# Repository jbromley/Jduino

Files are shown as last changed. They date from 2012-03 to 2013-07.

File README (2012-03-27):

Jduino
======

These are the design files (EAGLE 6) for a simple, homebrew Arduino
clone. It uses the Arduino clone from chapter 6 of _Arduino Robotics_
and seeks to make a smaller board that preserves the Arduino
outline. Additionally, I hope to add the following features:

 * power switch,
 * power protection diode,
 * smaller L4931 LDO voltage regulator,
 * right angle FTDI port on edge of board so programming can be done
   with a shield attached.

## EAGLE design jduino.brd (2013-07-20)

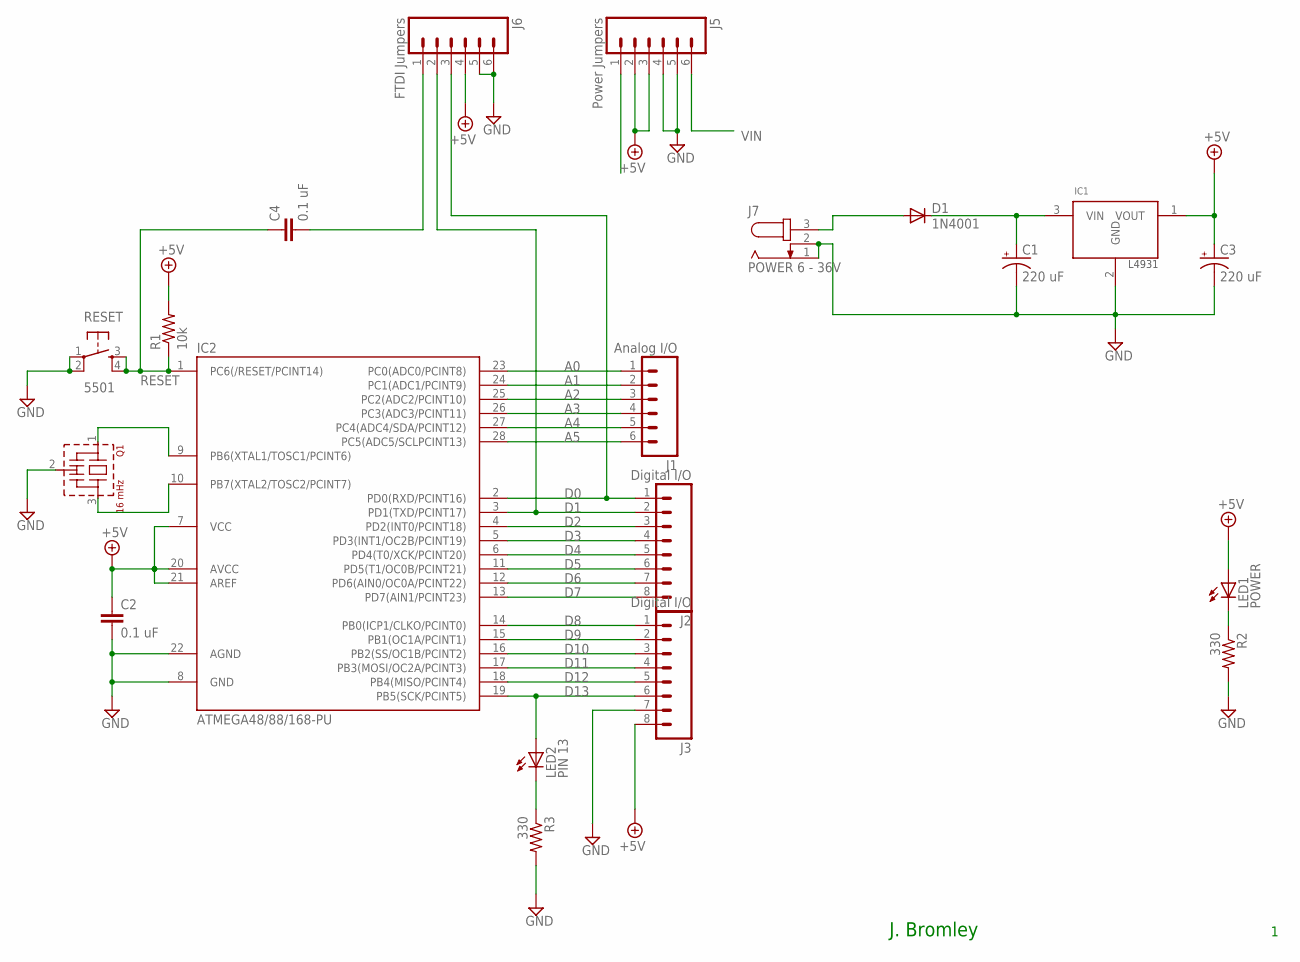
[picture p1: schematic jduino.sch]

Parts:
C1, C3: 220 uF; CPOL-RADIAL-10UF-25V
C2, C4: 0.1 uF; CAP-PTH-SMALL
D1: 1N4001; DIODE-1N4001
IC1: L4931; TO-92
IC2: ATMEGA48/88/168-PU; DIL28-3
J1: Analog I/O; 1X06
J2, J3: Digital I/O; 1X08
J5: Power Jumpers; 1X06
J6: FTDI Jumpers; 1X06
J7: POWER 6 - 36V; SPC4078
LED1: POWER; LED3MM
LED2: PIN 13; LED3MM
Q1: 16 mHz; CSTLS_X
R1: 10k; AXIAL-0.3
R2, R3: 330; AXIAL-0.3
RESET: 5501; TACTILE-PTH

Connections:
+5V: C2.1, C3.1 (+), IC1.1 (VOUT), IC2.7 (VCC), IC2.20 (AVCC), IC2.21 (AREF), J3.8, J5.2, J5.3, J6.4, LED1.A, R1.P$2 (2)
A0: IC2.23 (PC0(ADC0/PCINT8)), J1.1
A1: IC2.24 (PC1(ADC1/PCINT9)), J1.2
A2: IC2.25 (PC2(ADC2/PCINT10)), J1.3
A3: IC2.26 (PC3(ADC3/PCINT11)), J1.4
A4: IC2.27 (PC4(ADC4/SDA/PCINT12)), J1.5
A5: IC2.28 (PC5(ADC5/SCLPCINT13)), J1.6
D0: IC2.2 (PD0(RXD/PCINT16)), J2.1, J6.3
D1: IC2.3 (PD1(TXD/PCINT17)), J2.2, J6.2
D2: IC2.4 (PD2(INT0/PCINT18)), J2.3
D3: IC2.5 (PD3(INT1/OC2B/PCINT19)), J2.4
D4: IC2.6 (PD4(T0/XCK/PCINT20)), J2.5
D5: IC2.11 (PD5(T1/OC0B/PCINT21)), J2.6
D6: IC2.12 (PD6(AIN0/OC0A/PCINT22)), J2.7
D7: IC2.13 (PD7(AIN1/PCINT23)), J2.8
D8: IC2.14 (PB0(ICP1/CLKO/PCINT0)), J3.1
D9: IC2.15 (PB1(OC1A/PCINT1)), J3.2
D10: IC2.16 (PB2(SS/OC1B/PCINT2)), J3.3
D11: IC2.17 (PB3(MOSI/OC2A/PCINT3)), J3.4
D12: IC2.18 (PB4(MISO/PCINT4)), J3.5
D13: IC2.19 (PB5(SCK/PCINT5)), J3.6, LED2.A
GND: C1.2 (-), C2.2, C3.2 (-), IC1.2 (GND), IC2.8 (GND), IC2.22 (AGND), J3.7, J5.4, J5.5, J6.5, J6.6, J7.1, J7.2, Q1.2 (VSS), R2.P$2 (2), R3.P$2 (2), RESET.1, RESET.2
unnamed: C4.2, J6.1
unnamed: D1.A, J7.3
unnamed: IC2.10 (PB7(XTAL2/TOSC2/PCINT7)), Q1.3
unnamed: LED2.K (C), R3.P$1 (1)
unnamed: IC2.9 (PB6(XTAL1/TOSC1/PCINT6)), Q1.1
unnamed: C1.1 (+), D1.C, IC1.3 (VIN)
unnamed: LED1.K (C), R2.P$1 (1)
RESET: C4.1, IC2.1 (PC6(/RESET/PCINT14)), J5.1, R1.P$1 (1), RESET.3, RESET.4
VIN: J5.6

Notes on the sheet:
J. Bromley

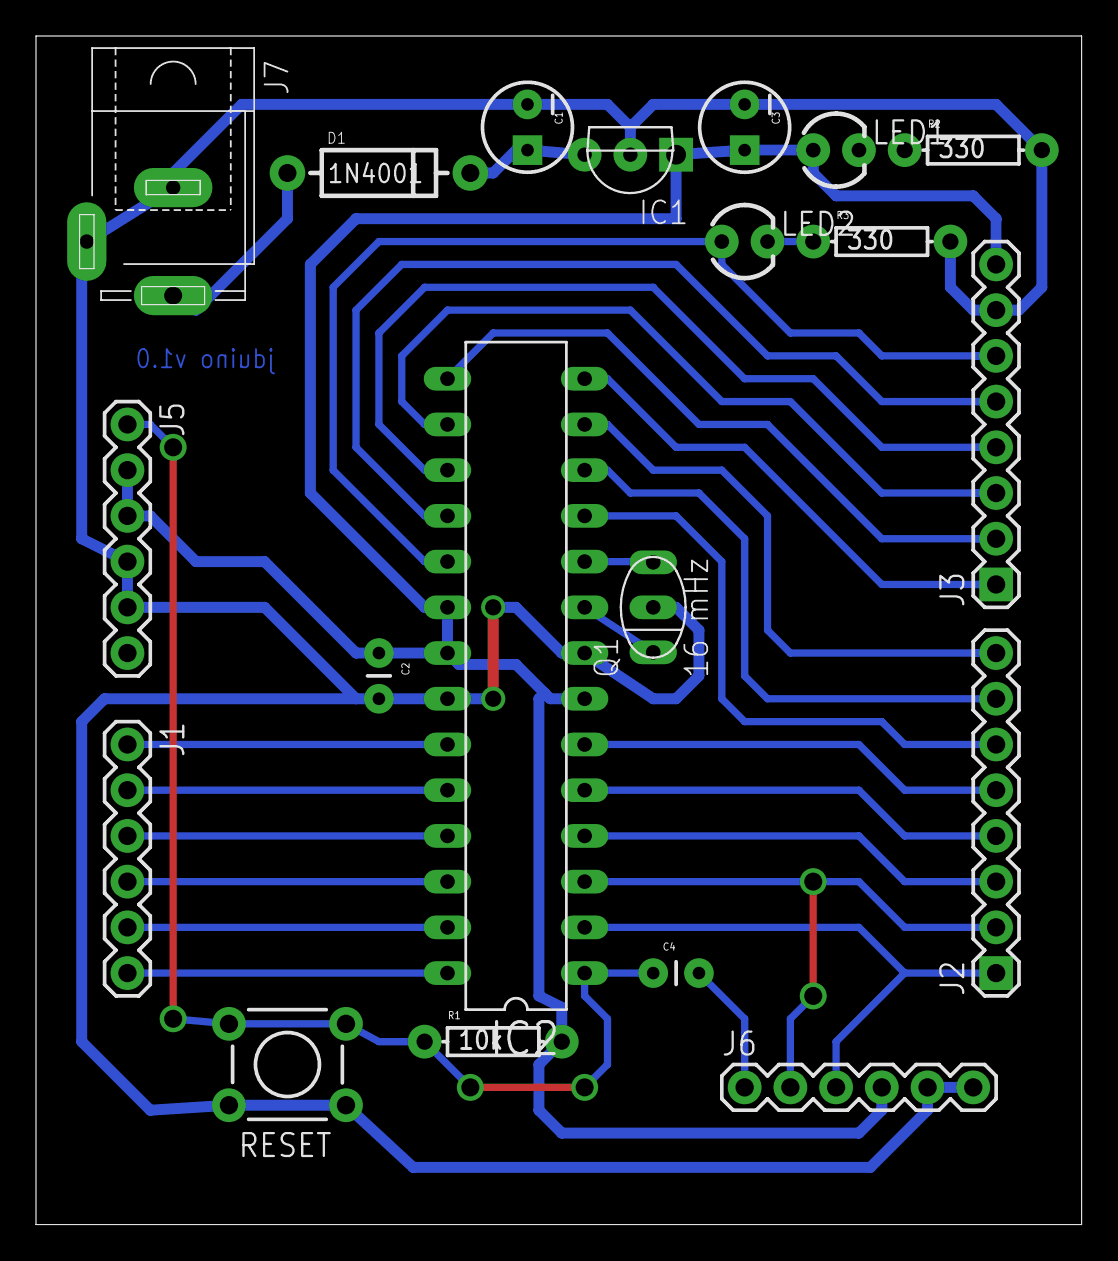
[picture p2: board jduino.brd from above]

Board: 2 copper layers, 58.1 x 66.0 mm, 20 parts (0 on the bottom side), 30 nets.

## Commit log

2012-03-27 Initial import.
    Initial import of the design files from the _Arduino Robotics_ book.
    [jduino.brd, jduino.sch]
2012-03-30 Added power elements.
    Added a protection diode and a power switch. Also swapped out the
    7805 for a LDO regulator.
    [jduino.brd, jduino.sch]
2012-03-30 Initial complete version.
    Routed D9 - D13, GND, and AREF to the headers. Rotated the FTDI
    header to be able to use a right angle header. Two jumpers remain.
    [jduino.brd]
2012-04-11 Replaced Euro-stype capacitors.
    Replaced the large reset capacitors with smaller-package 0.1 uF
    capacitors.
    [jduino.brd, jduino.sch]
2012-04-11 Hand routed some pins.
    I hand-routed pins 3 through 5 and 23 through 28, since these should
    be straight-shots. Then auto routed the remaining traces. The board
    still needs significant cleanup.
    [jduino.brd]
2012-04-12 Finished one-sided layout.
    Completed a one-sided layout of the board that only requires three
    jumpers.
    [jduino.brd, jduino.sch]
2012-04-12 Recentered circuit on board.
    That last revisions left some traces too near the edge of the
    board. Moved the circuit to have at least 0.1 inch clearance on all
    board edges.
    [jduino.brd]
2012-04-12 Reset adjustments and aesthetic improvements.
    Connected reset pin on power jumper before DTR capacitor. Cleaned
    up extraneous label and added a frame to the schematic.
    [jduino.brd, jduino.sch]
2012-05-08 Added mounting holes to the board.
    [jduino.brd, jduino.sch]
2013-07-03 Completed layout.
    Completed the board layout and sizing. Needed to include four top-side
    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
    [jduino.brd, jduino.sch]
2013-07-03 Added a ground plane.
    Made the ground plane encompass the whole board.
    [jduino.brd, jduino.sch]
2013-07-05 Final fixes for printing.
    Replaced power IC with 2931. Added an LED on pin 13.
    [jduino.brd, jduino.sch]
2013-07-08 Small fixes to the circuit.
    [jduino.brd, jduino.sch]
2013-07-13 Cleaned up area around reset button.
    Rotated the reset button. Tied extra button terminals to the live
    terminals.
    [jduino.brd, jduino.sch]
2013-07-20 Fixed pad sizes.
    Replaced original parts from the Arduino robotics book with components
    from the SparkFun libraries so that pads would be properly sized.
    [jduino.brd, jduino.sch]

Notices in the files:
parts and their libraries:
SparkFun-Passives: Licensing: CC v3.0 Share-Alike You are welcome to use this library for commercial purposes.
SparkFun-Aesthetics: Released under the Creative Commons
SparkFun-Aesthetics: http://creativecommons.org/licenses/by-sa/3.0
